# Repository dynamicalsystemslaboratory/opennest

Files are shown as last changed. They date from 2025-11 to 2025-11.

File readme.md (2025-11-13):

**Title** *OpenNest: A modular experimental setup for long term studies of collective behavior in ants*\
**Authors** Darryl Linardi, Michael Napoli, Roxy Nadim, Simon Garnier, Maurizio Porfiri\
**Presented At** *Animal Behavior Live, 2025*

---

### Directory

* `acrylic/` Contains the acrylic lids corresponding to the arena and outer triangle compartments.
    * `hexagon-chamber.DXF` Stencil for cutting acrylic lids for the large hexagonal chamber.
    * `outer-triangle.DXF` Stencil for cutting acrylic lids for the outer triangular chamber.
* `print3d/` Contains all the necessary STL files, ready for any 3D printer.
    * `gate.STL` Print file for the gates (universal to all chambers).
    * `hexagon-chamber.STL` Print file for the large hexagonal chamber.
    * `inner-triangle_wall-N.STL` Print file for the inner triangular chambers. Each alternative has an index which indicates the number of walls.
    * `key-length.STL` Print file for the connecting keys. Two alternatives are provided: short and long. We recommend the short key to improve chamber security.
    * `outer-triangle.STL` Print file for the outer triangular chamber.
* `starter.STL` Our **recommended** print for any first-time users. Pieces are selected to help you understand how the mechanisms work.

---

### Instructions

The OpenNest environment can printed and prepared in just a few simple steps:

0. **Necessary Materials**
    * Before beginning the build, you will need:
        * M2 screws (we recommend size M2*6, but an assorted pack is linked [here](https://www.amazon.com/Screws-Metric-Machine-Plated-Washers/dp/B0D3X4LJD2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)).
        * Heat-set threaded inserts (compatible with M2 screws; [here](https://www.amazon.com/HANGLIFE-Heat-Set-Threaded-Printing-Components/dp/B0CS6XJSSL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)).
        * Acrylic sheets (we recommend `+1/16` thick acrylic [here](https://www.amazon.com/Egofine-Plexiglass-Transparent-Crafting-Replacement/dp/B099DBW1PG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))
        * Soldering iron.
    * For first time prints we recommend using the `starter.STL` file!
        <p align="center">
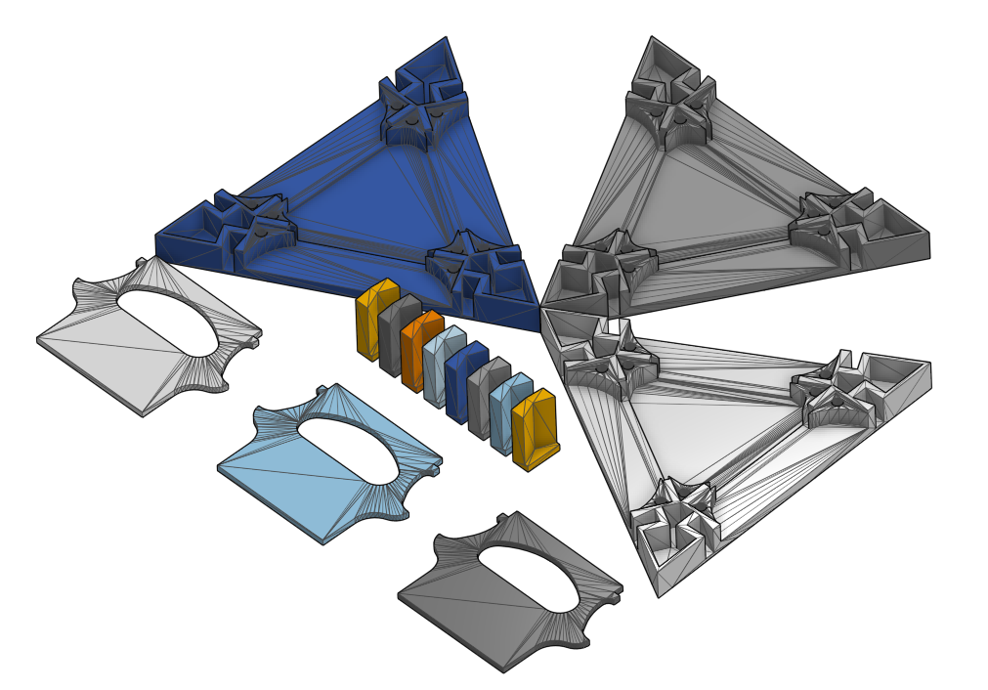
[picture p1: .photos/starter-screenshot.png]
Starter Print
        
        </p>
1. **Download or Clone the Repository**
    * Download the latest version of OpenNest from the official repository:
   ```bash
   git clone https://github.com/dynamicalsystemslaboratory/opennest.git
2. **3D Print the Nest Components**
    * Drag and drop the appropriate files from the `print3d/` directory into your favorite 3D print software.
    * Print each part using your preferred 3D print settings. If possible, we recommend white filament to make ants distinguishable from the background during videos.
3. **Install Heat-set Threaded Inserts**
    * Rest one of the threaded inserts above each of the holes located on the 3D print.
        <!-- <p align="center">
        <img src=".photos/20251110_133927.jpg" alt="Key Unpressed" height="250px"/>
        </p> -->
    * Once heated up, gently press the threaded insert into the hole. Once flush with the plastic remove the soldering iron.
        <p align="center">
        <img src=".photos/20251110_134035.jpg" alt="Soldering Iron Press" height="250px"/>
        </p>
    * *Optional*: We recommend also have a flat surface available that you can use to press the threaded insert flush with the plastic after you remove the soldering iron and while it cools.
        * In some cases, the heat of the soldering iron causes the plastic to expand upon removal, pushing the threaded insert back out of the hole.
        <p align="center">
        <img src=".photos/20251110_134107.jpg" alt="Knife Press" height="250px"/>
        <img src=".photos/20251110_134204.jpg" alt="Finished Inserts" height="250px"/>
        </p>
3. **Cut Acrylic Lids**
    * All the necessary stencils are provided in `acrylic/`.
4. **Assemble the Nest**
    * At this point, you are ready to assemble the nest!
    * Use the keys to connect the various compartment types.
        <p align="center">
        <img src=".photos/20251110_151157.jpg" alt="Key Unpressed" height="250px"/>
        <img src=".photos/20251110_151159.jpg" alt="Key Pressed" height="250px"/>
        </p>
    * Shut the gates to close off pathways for escape!
        <p align="center">
        <img src=".photos/20251110_151228.jpg" alt="Gate Unpressed" height="250px"/>
        <img src=".photos/20251110_151242.jpg" alt="Gate Pressed" height="250px"/>
        </p>

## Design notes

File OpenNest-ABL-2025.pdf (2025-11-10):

# OpenNest

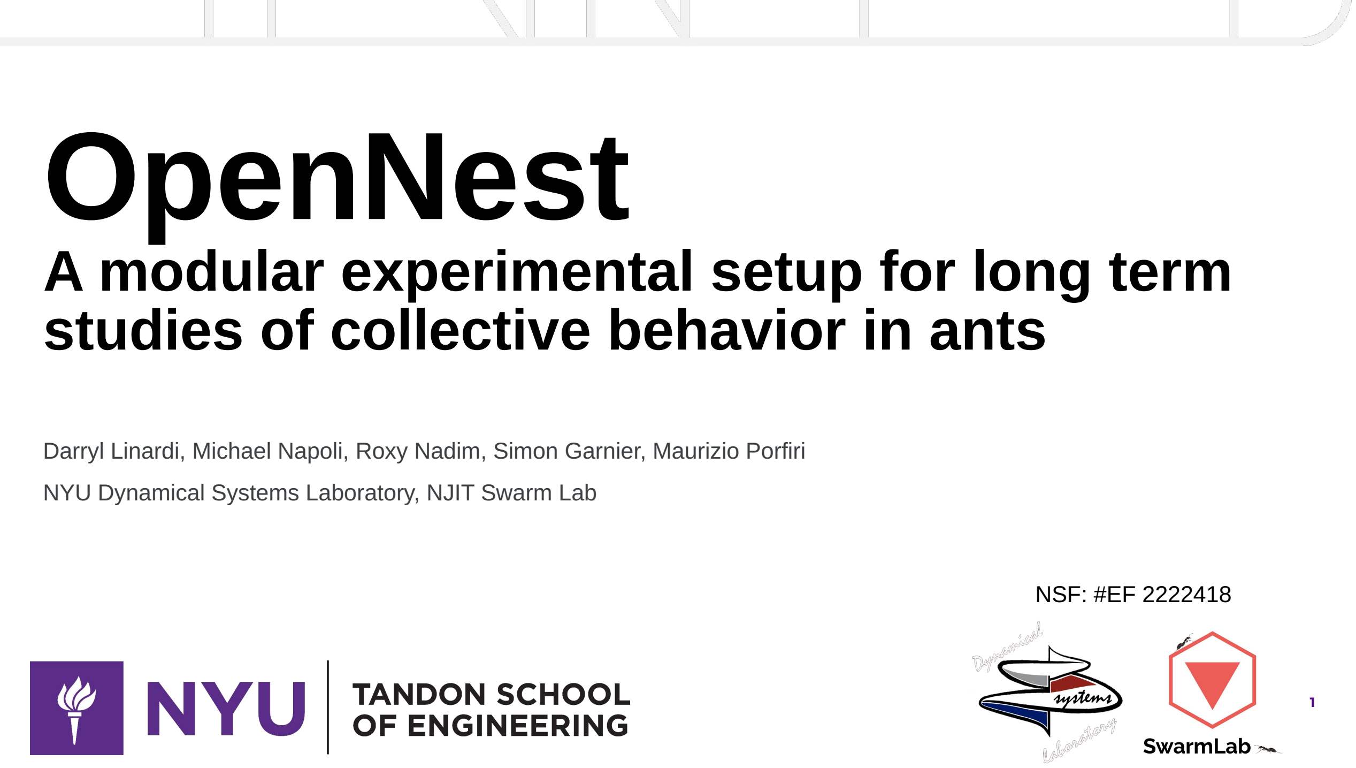
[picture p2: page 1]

1

# A modular experimental setup for long term studies of collective behavior in ants

Darryl Linardi, Michael Napoli, Roxy Nadim, Simon Garnier, Maurizio Porfiri NYU Dynamical Systems Laboratory, NJIT Swarm Lab

NSF: #EF 2222418

# Existing Experimental Setups

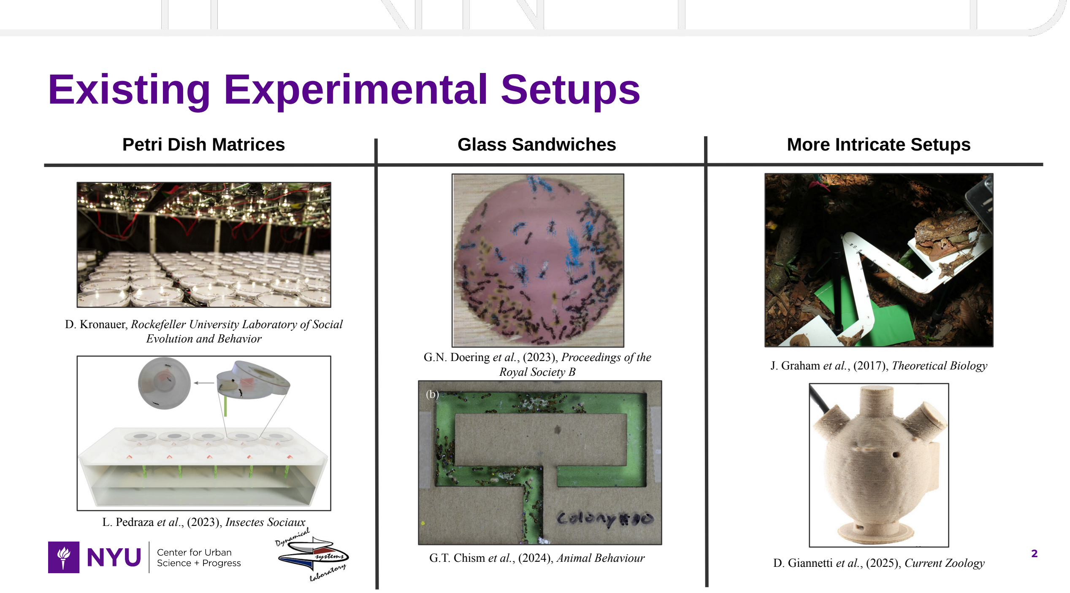
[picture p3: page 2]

2

J. Graham et al., (2017), Theoretical Biology

Petri Dish Matrices

D. Kronauer, Rockefeller University Laboratory of Social Evolution and Behavior
L. Pedraza et al., (2023), Insectes Sociaux
Glass Sandwiches | More Intricate Setups

G.N. Doering et al., (2023), Proceedings of the Royal Society B

G.T. Chism et al., (2024), Animal Behaviour | D. Giannetti et al., (2025), Current Zoology

# OpenNest: A Modular Solution

## 1. Connector Keys

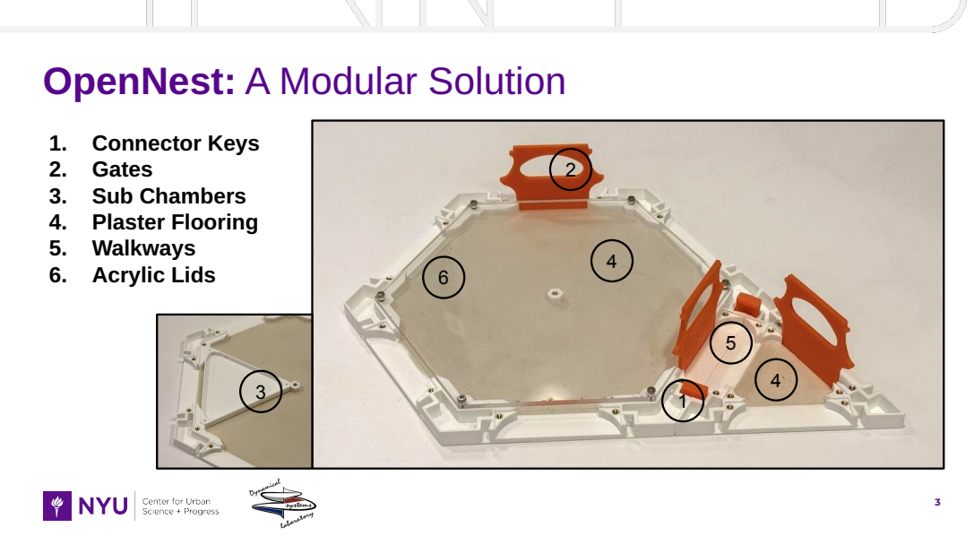
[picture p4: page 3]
2. Gates 3. Sub Chambers 4. Plaster Flooring 5. Walkways 6. Acrylic Lids

# Preventing Jailbreaks

| Internal force in the key bits pull chambers together at all times, closing any gaps.

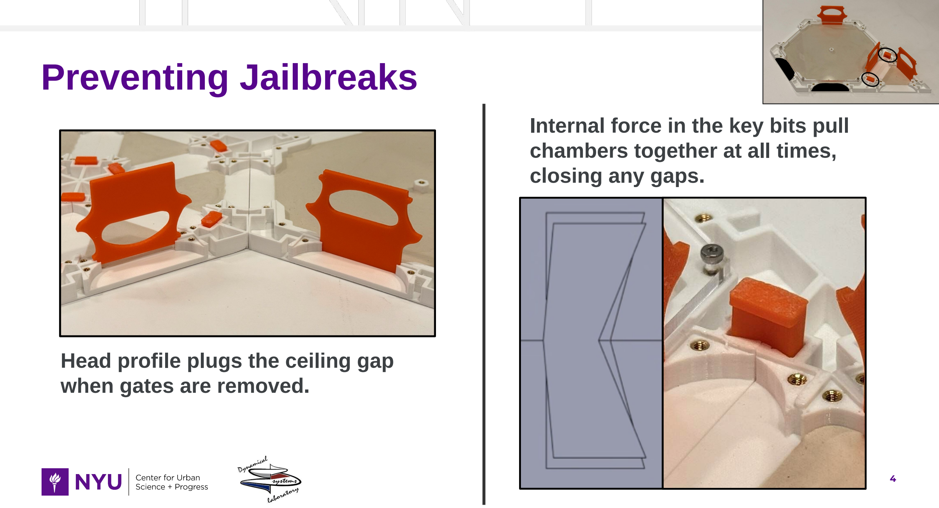
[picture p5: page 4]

4

## Head profile plugs the ceiling gap

when gates are removed.

# Symmetry Creates Adaptability

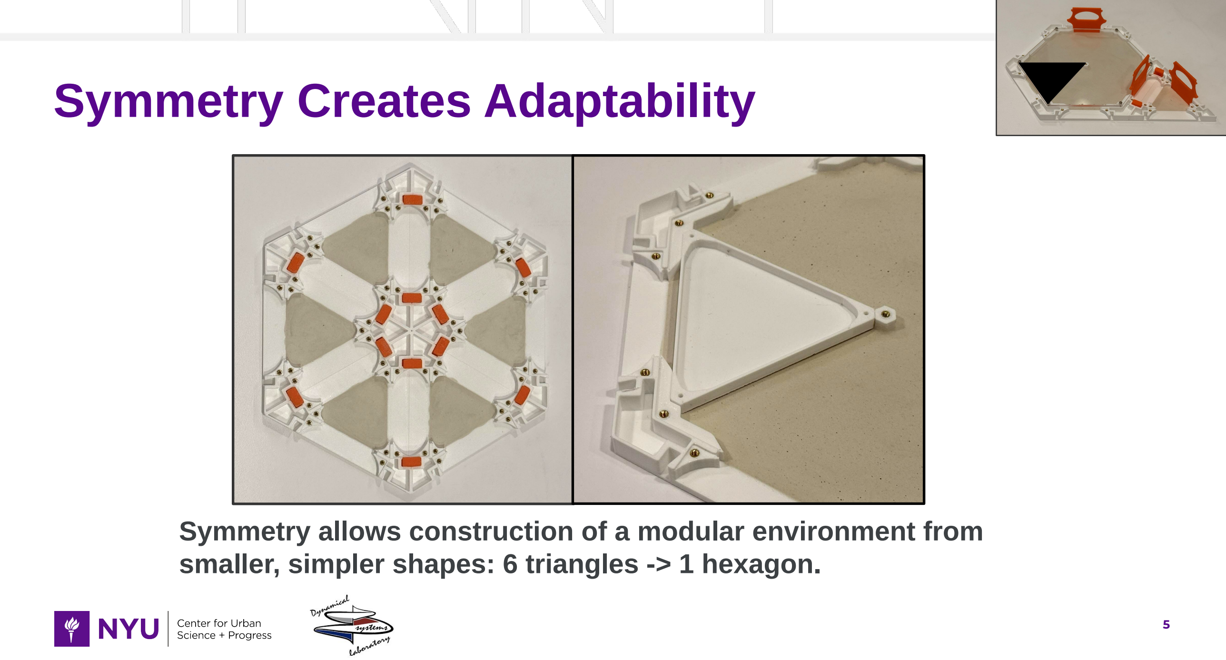
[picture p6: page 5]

5

## Symmetry allows construction of a modular environment from

smaller, simpler shapes: 6 triangles -> 1 hexagon.

# Keeping Residents Comfortable

## Plaster floors

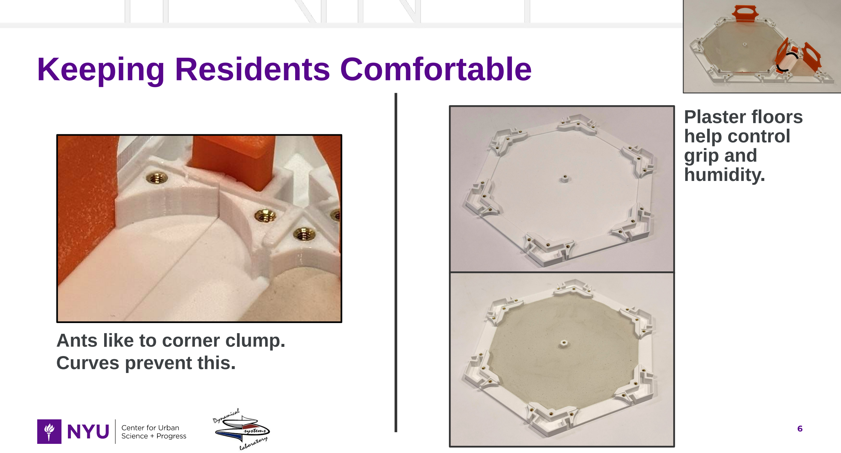
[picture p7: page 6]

6

Ants like to corner clump. Curves prevent this.

## help control grip and

humidity.

7

# Future Experiments Task Allocation Experiments

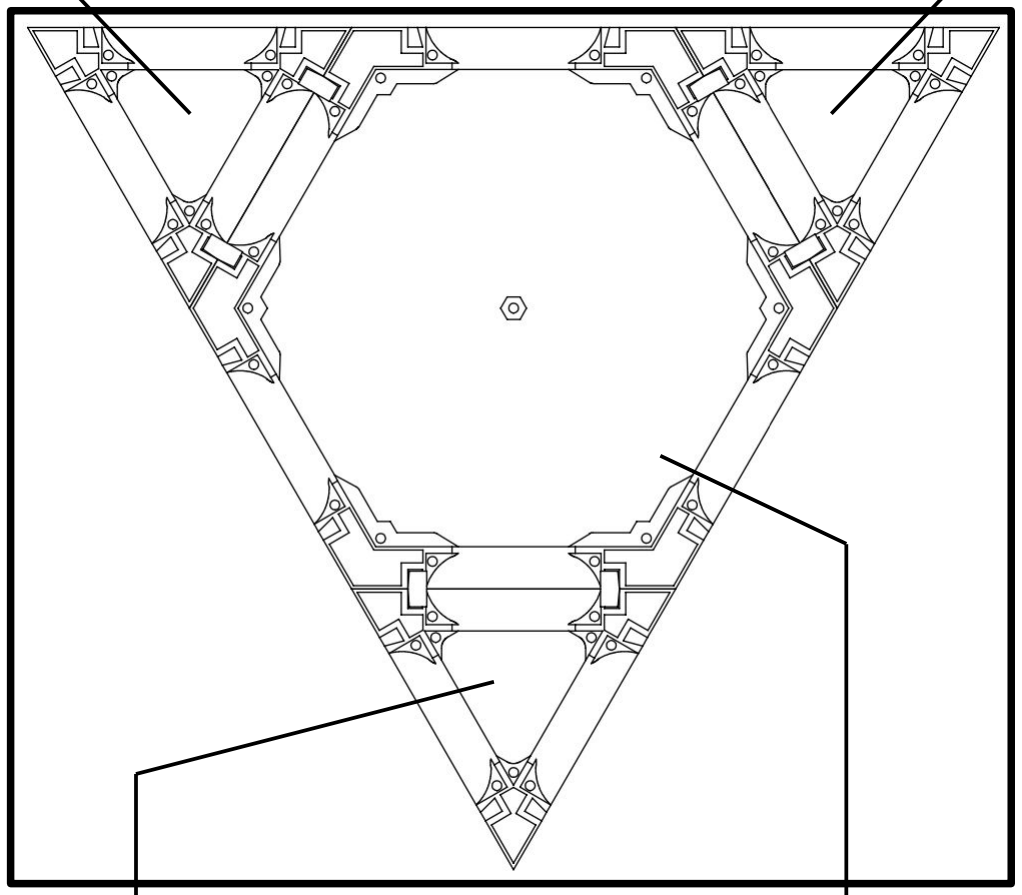
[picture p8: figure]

Nest Chamber

Task 1 | Task 2

Exploration Chamber

Foraging Area 1 | Foraging Area 2

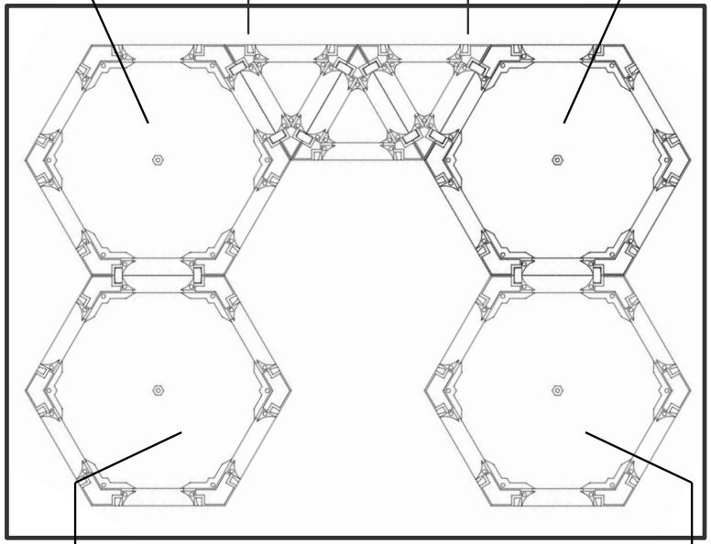
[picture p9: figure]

Nest Chamber 1 | Nest Chamber 2

Removable Bridge

Nest Interaction Experiments

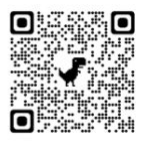
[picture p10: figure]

8

# Questions?

Maurizio Porfiri

Institute Professor
Director of CUSP
Department of Mechanical and Aerospace Engineering Department of Biomedical Engineering Room 1326,
370 Jay Street
| 646-997-3681
mporfiri@nyu.edu
https://wp.nyu.edu/dsl/

Contact

## Github Repository: https://github.com/dynamicalsystemslaboratory/opennest.git

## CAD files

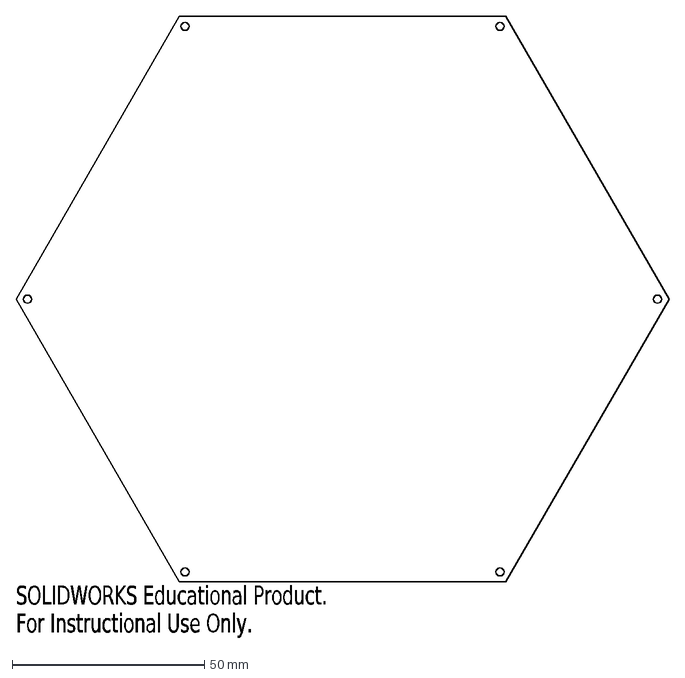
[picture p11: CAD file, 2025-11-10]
acrylic/hexagon-chamber.DXF
SOLIDWORKS Educational Product.
For Instructional Use Only.

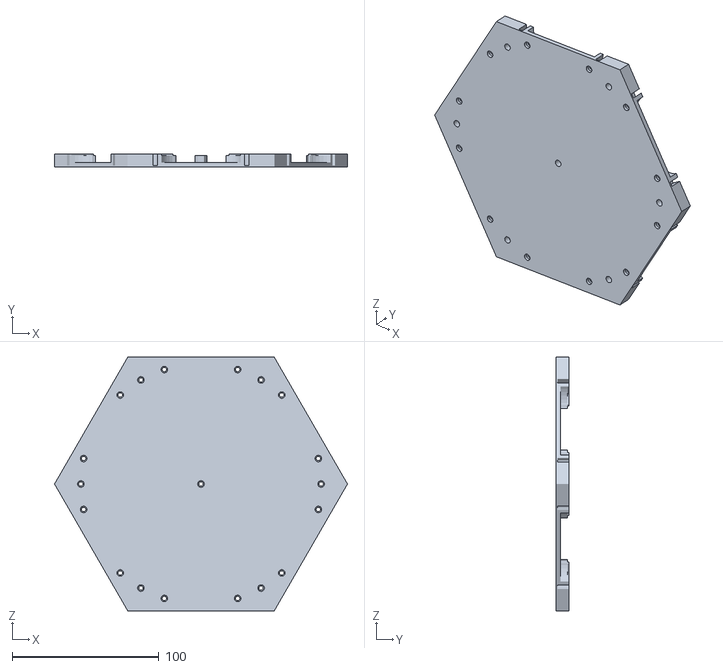
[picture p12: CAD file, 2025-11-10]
print3d/hexagon-chamber.STL
200.0 x 9.00 x 173.2

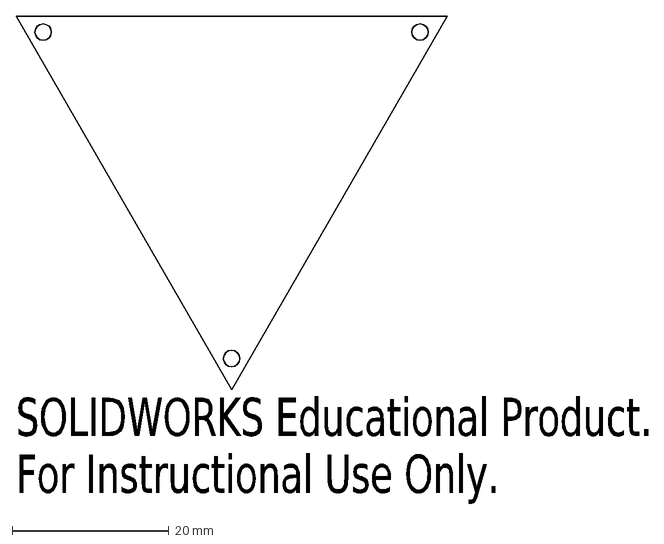
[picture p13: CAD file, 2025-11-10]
acrylic/outer-triangle.DXF
SOLIDWORKS Educational Product.
For Instructional Use Only.

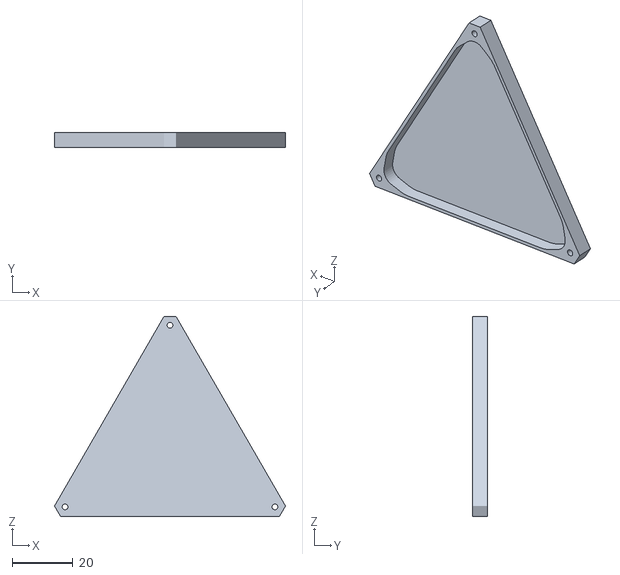
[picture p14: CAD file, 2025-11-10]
print3d/inner-triangle_wall-3.STL
76.0 x 5.00 x 65.8

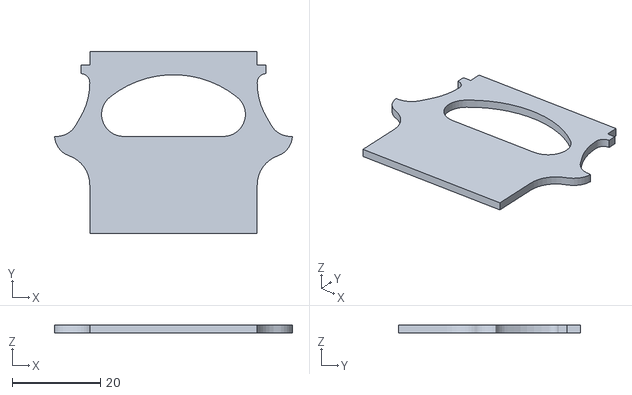
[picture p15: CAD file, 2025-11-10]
print3d/gate.STL
54.0 x 41.2 x 1.80

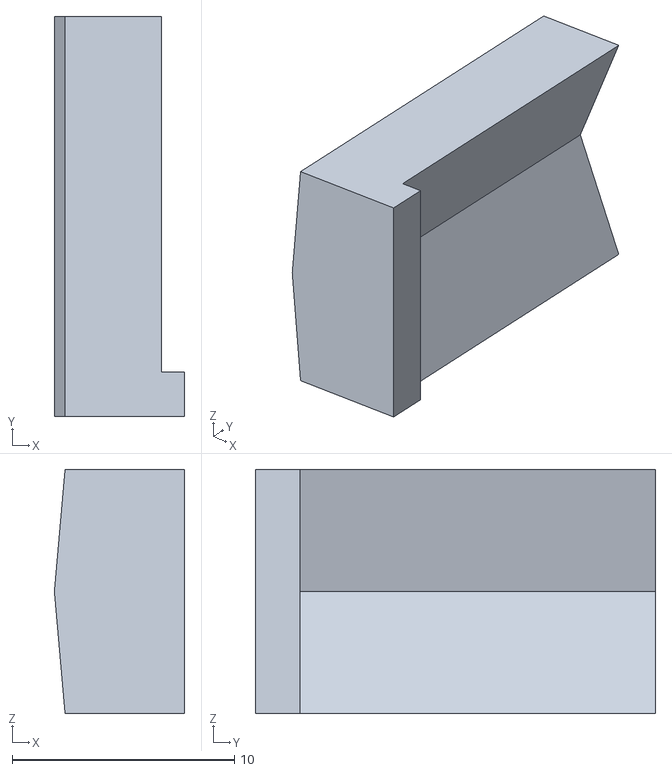
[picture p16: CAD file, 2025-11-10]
print3d/key-long.STL
5.86 x 18.0 x 11.0

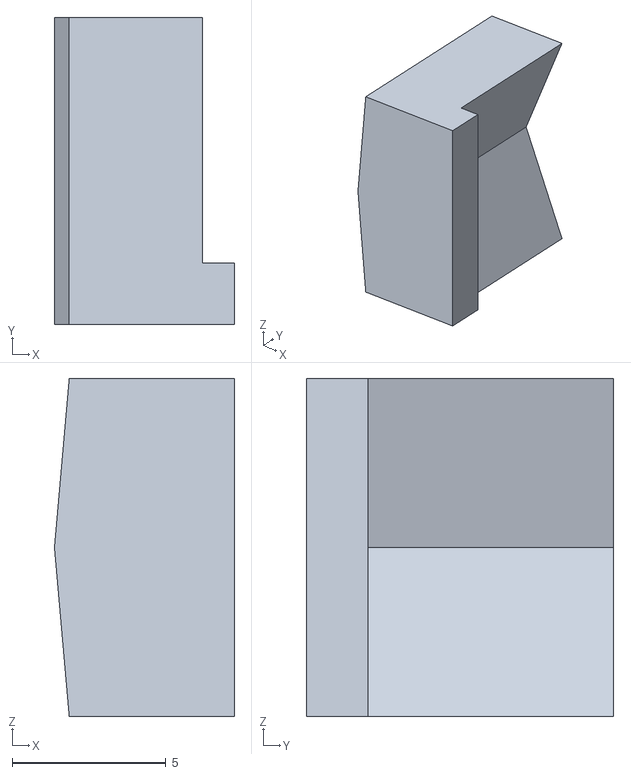
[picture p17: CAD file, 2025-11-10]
print3d/key-short.STL
5.86 x 10.0 x 11.0

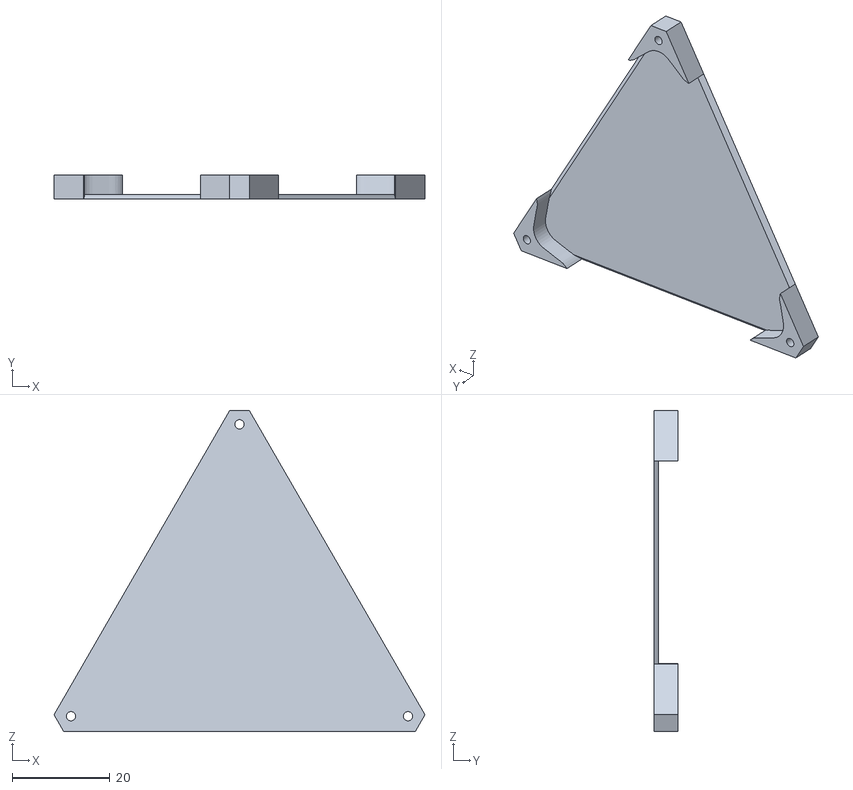
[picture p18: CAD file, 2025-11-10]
print3d/inner-triangle_wall-0.STL
76.0 x 5.00 x 65.8

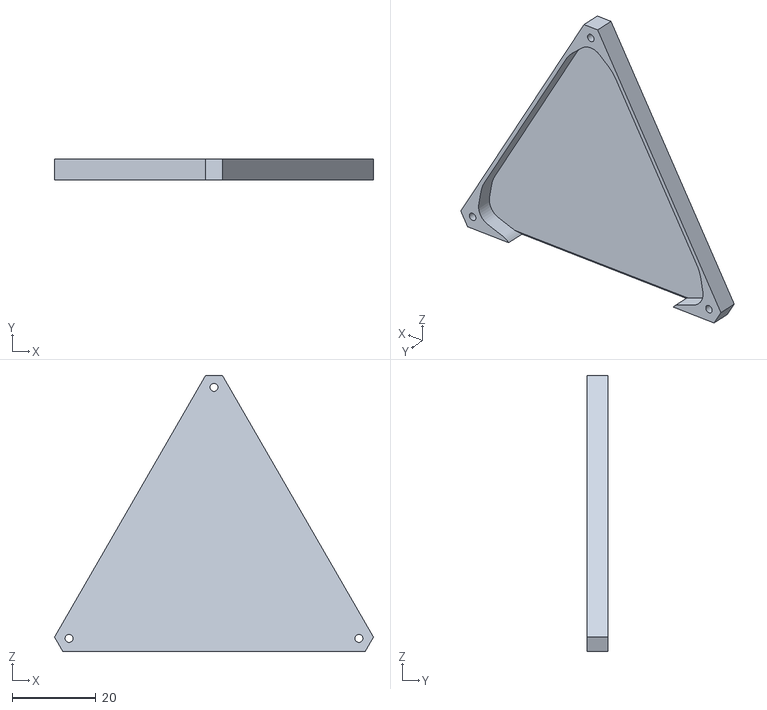
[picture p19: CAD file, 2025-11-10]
print3d/inner-triangle_wall-2.STL
76.0 x 5.00 x 65.8

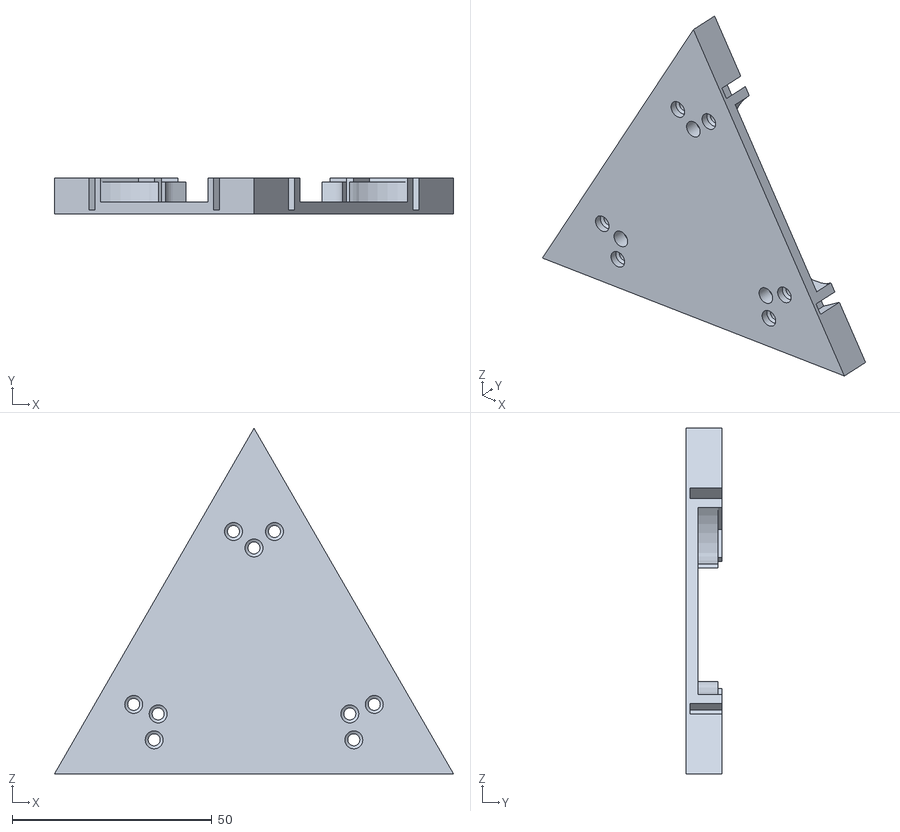
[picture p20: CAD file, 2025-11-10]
print3d/outer-triangle.STL
100.0 x 9.00 x 86.6

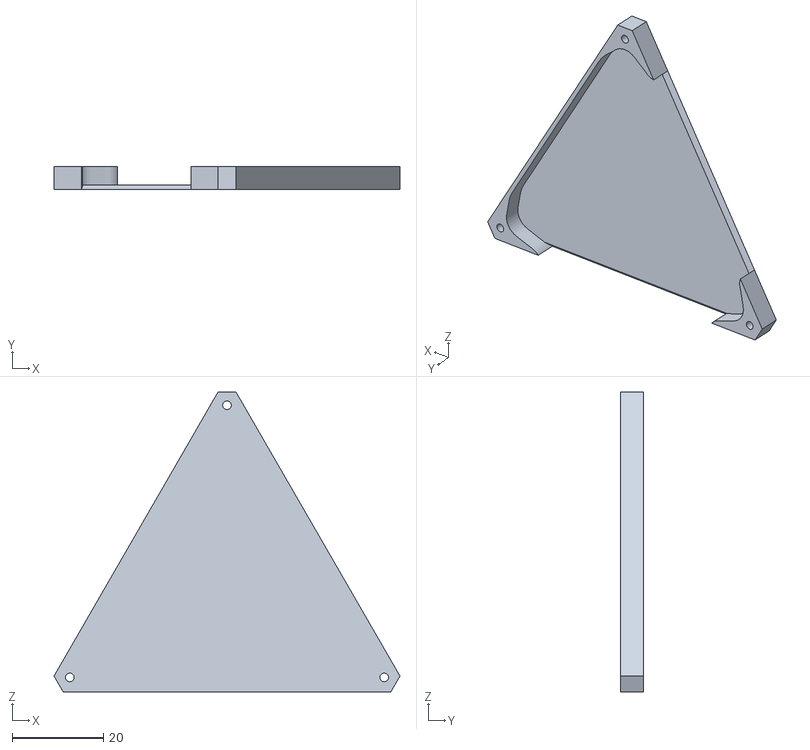
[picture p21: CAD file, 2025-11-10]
print3d/inner-triangle_wall-1.STL
76.0 x 5.00 x 65.8
